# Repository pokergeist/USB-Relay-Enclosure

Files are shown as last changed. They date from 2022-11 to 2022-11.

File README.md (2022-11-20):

# USB Relay Enclosure for<br>DSD Tech SH-UR01A

## Overview

The "DSD TECH  USB Relay Controller for Computer and Laptop (1CH)" lets you control a single SPDT relay via USB. I purchased my device on [Amazon](https://smile.amazon.com/dp/B09PYML6Q7). It comes (mostly) enclosed in a transparent blue case with the relay and screw terminals exposed, along with the back half of the board. The client preferred that the internals not be so accessible.

There are a number of similar designs without cases which probably use the the same board size. If the board size is different, just modify board_x, board_y, and board_height in SCAD/DSD-Encl-common.scad in OpenSCAD and render DSD-Encl-base.scad and save the STL file (Windows F5, F6, F7).

## Status

| Date | Status |
| :---: | --- |
| 2022-11-20 | Done. |
| 2022-11-18 | First release. |

## ToDo List

* -none-

## Board Extraction

The case is a clamshell design that separates with the patient use of a spudger or pen knife. There are (6) small acrylic pins that hold the halves together. The board is well supported and positioned within the case.

See the photos in [DSD-orig](assets/DSD-orig).

## The Enclosure via OpenSCAD

My enclosure was developed using OpenSCAD, a programming language that is used to render 3-D objects for visualization and export to a standard STL file, which can then be used for 3-D printing. Elements are defined parametrically so they can be modified easily and immediately visualized and printed.

My OpenSCAD code uses some Booleans that can help visualize the package.

```
SHOW_BOARD = false;    // false before exporting STL!
HIDE_SHELL = false;    // for visualizing internals
```

SHOW_BOARD shows the printed circuit board and some components. HIDE_SHELL hides the shell mostly so you can see the internal structures. OpenSCAD has a transparent feature but it doesn't seem to work well with the rounded corners.

I uses color() to highlight areas of interest. There's a final color("MediumSpringGreen") (~line 31) that applies to the entire object. This needs to be commented out to see the component colors.

I added a hz_pins_2() function to just print pins on the left (terminal block) side and left the original hz_pins() function in place.

## Files

There are two files sets that I provide:

* Enclosure Files:
  * (3) .scad files for the bottom shell, lid, and common dimensions.
* Library files with routines for unit conversions and generating circuit board images.

### External Resources

OpenSCAD tool: [OpenSCAD.org](https://openscad.org/)

The Belfry OpenSCAD Library [revarbat/BOSL](revarbat/BOSL).

Place the BOSL and mylibs dirs in your OpenSCAD libraries directory (e.g., Documents/OpenSCAD/libraries/).

### Photo

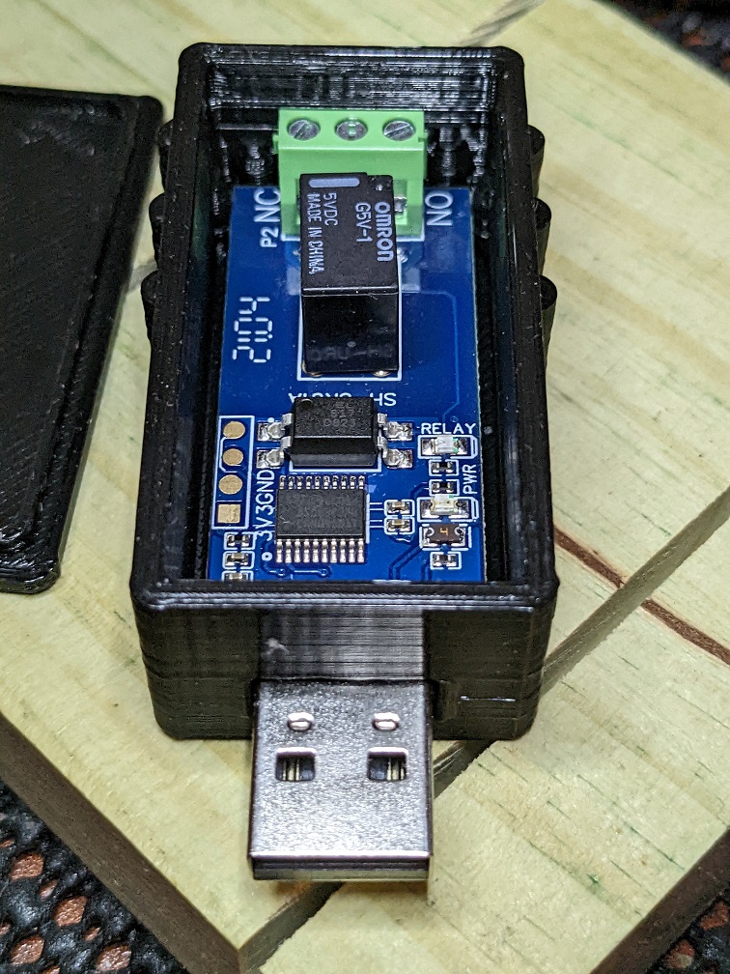
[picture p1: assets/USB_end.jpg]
DSD Item


## Fitment

The DSD board snaps snuggly into place once the USB plug end is carefully inserted through the USB window opposite of the ribbed end. Then just press down and everything should snap gently into place. There is a cable port opposite the USB window that allows you to insert wires into the NO, COM, and NC ports such that you can secure them with the terminal screws from above.

It may help to shorten the leads of the wire terminal connector with a pair of "nippy" or flush cutter pliers so that they don't catch on the edge of the enclosure, but new lower case and larger USB window has resolved the issue for me.

The lid simply snaps on.

## Operation

Relay terminals operate thusly:

* The **COM** (common) terminal is always connected to one (and only) of the other terminals at any given time.
* The **NC** (normally connected) terminal connects to the COM terminal whenever the relay **IS NOT** energized, and is isolated otherwise.
* The **NO** (normally open) terminal is normally isolated but connects to the COM terminal when the relay **IS** energized.

You would normally use the COM and NO terminals to simulate a switch. The contacts are not polarized so connect either contact (tip or ring if using 1/8"/3.5mm plugs).

For software operation please refer to vendor's documentation.

## Wire Connection Terminal

The three terminal wire connector appears to be a TE Connectivity/AMP #[1546551-3](https://www.digikey.com/short/0d5nwh74). 3-terminal 0.138"/3.5mm pitch, 120A 300V suitable for #16-28AWG wire ... or a clone. The screws are vertical so they can be manipulated with the lid removed.

The solder holes are not very big - TE recommends 1.1mm PCB holes for the connector's solder pins - just barely larger than #18AWG. I'll get a measurement on the solder holes soon.

## 1/8"/3.5mm Mono (TS) Cables

TS cables use the tip and sleeve contacts of a monophonic 1/8"/3.5mm "headphone" plug. A stereo plug is a "TRS" plug. TRS stands for Tip, Ring, & Sleeve since there is a third center contact giving you Left, Right and Ground. If you use a stereo (TRS) plug with a mono (TS) jack you'll have to verify whether the mono sleeve contact connects with the stereo sleeve (most common) or ring contact.

Here's a Digi-Key [search]() of 1/8" jacks terminated in a "pigtail", stripped wires. Length from 1 to 10'. Mono cables and jacks are scarce here - just be consistent if you use TRS hardware, or verify the mapping between TS and TRS hardware.

Amazon may offer a better selection - like this [one](https://smile.amazon.com/Fancasee-Replacement-Female-Connector-Repair/dp/B07Y8KR21P).

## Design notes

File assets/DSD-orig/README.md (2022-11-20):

# DSD Original Enclosure

## Images

### Complete

Here's the DSD device with the case separated slightly. You can see that the relay, terminal block, and about half of the board are exposed.

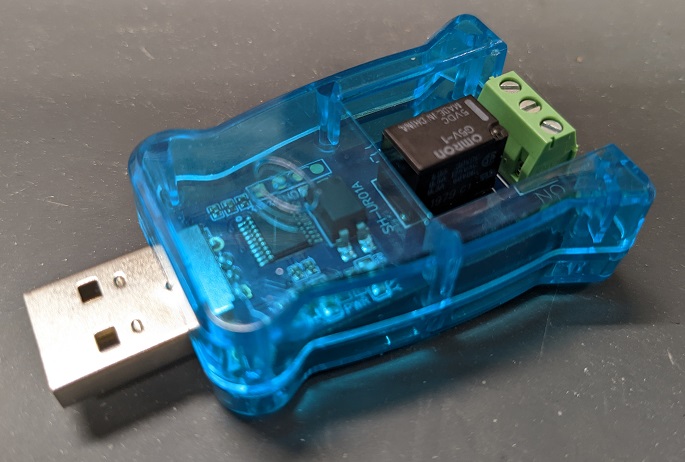
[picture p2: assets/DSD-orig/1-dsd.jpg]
complete


Here you can see the pins that hold the case together.

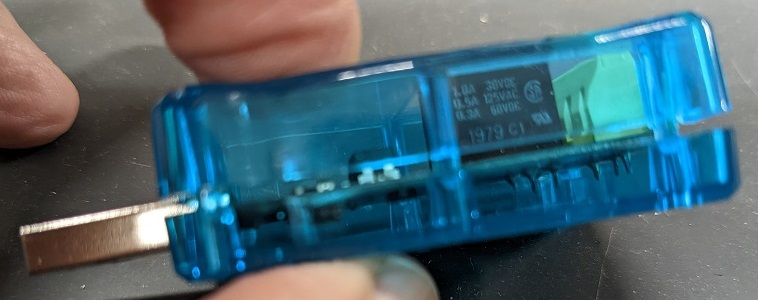
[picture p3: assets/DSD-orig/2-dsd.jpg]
pins


The top half of the case has been removed. It sits nicely supported and constrained in the base.

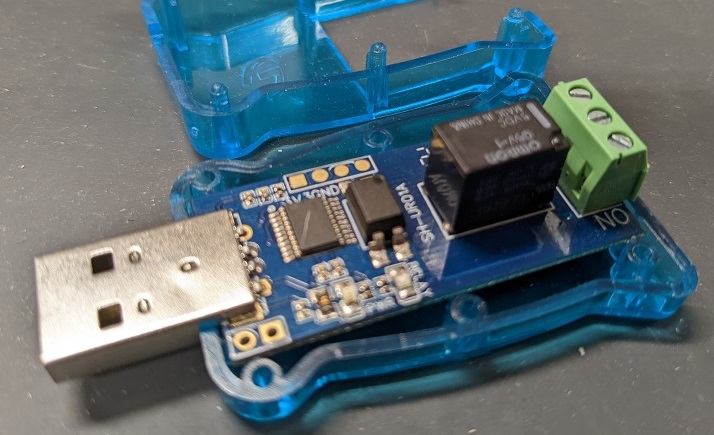
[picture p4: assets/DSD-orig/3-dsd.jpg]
in base


Here's the board with the case removed.

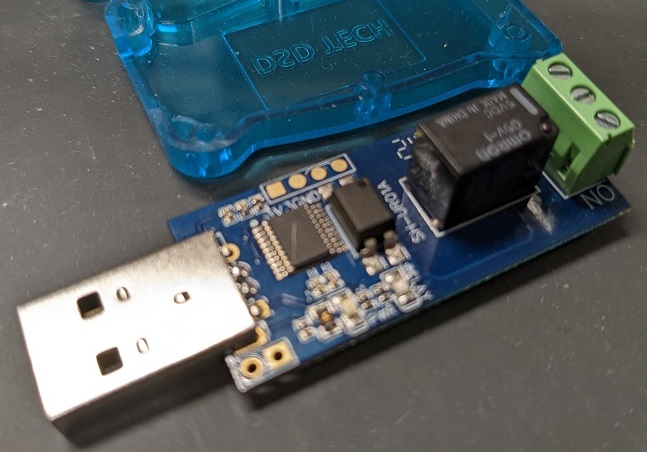
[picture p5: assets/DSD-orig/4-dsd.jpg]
board


And finally the bottom of the board. You can see labeling of the terminals and that there's no interference for board supports at the corners. The empty solder terminals connect to USB Vcc and ground.

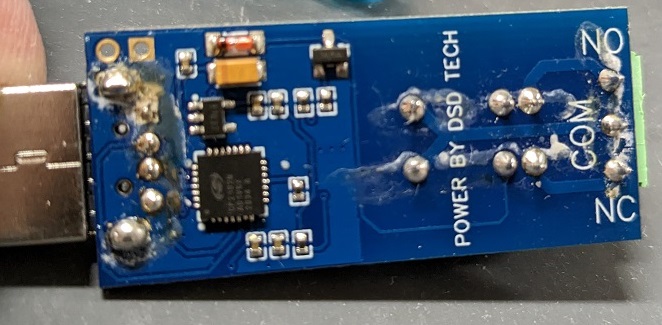
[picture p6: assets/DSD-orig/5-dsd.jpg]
bottom


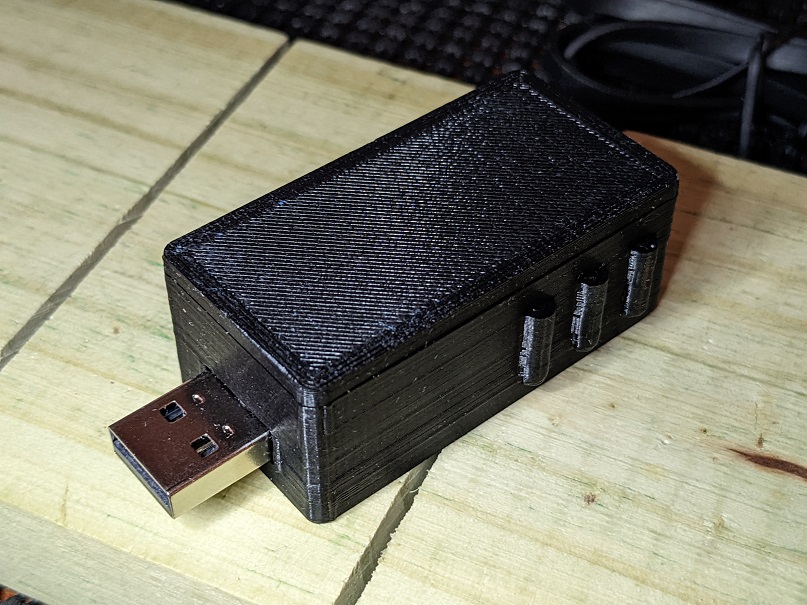
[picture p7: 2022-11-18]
assets/closed.jpg

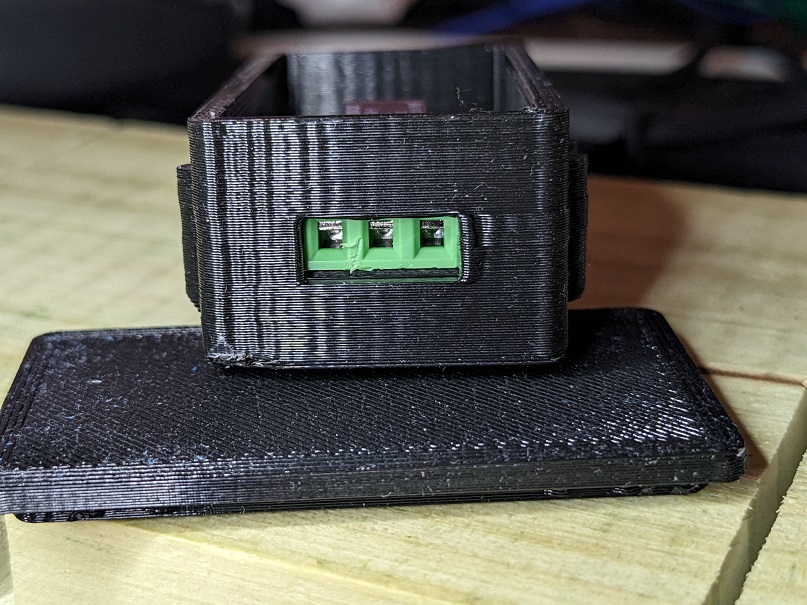
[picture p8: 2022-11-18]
assets/wire_terminals.jpg

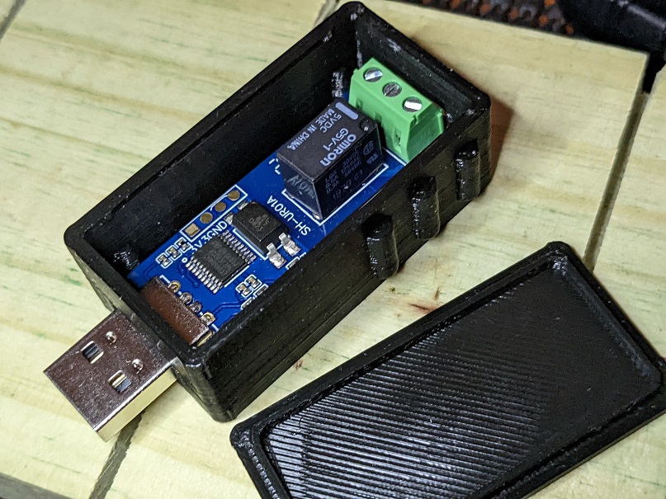
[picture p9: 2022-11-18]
assets/side.jpg

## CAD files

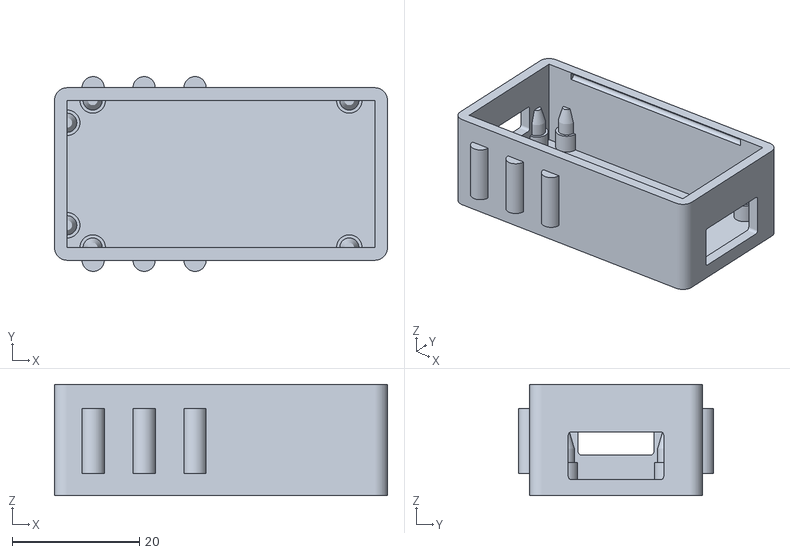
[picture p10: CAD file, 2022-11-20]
SCAD/STL/DSD-Encl-base.stl
52.3 x 30.6 x 17.5

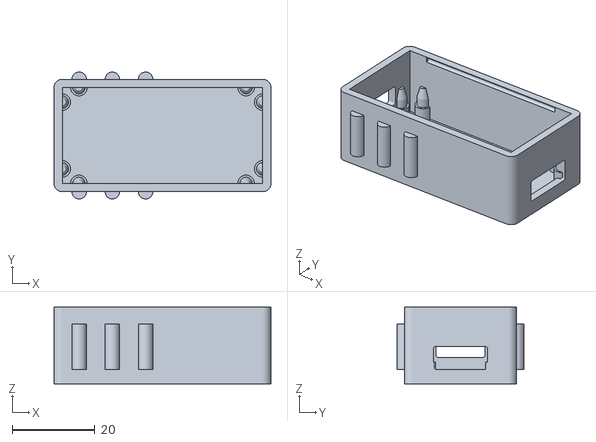
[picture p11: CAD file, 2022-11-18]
SCAD/STL/DSD-Encl-bot.stl
52.3 x 30.6 x 18.5

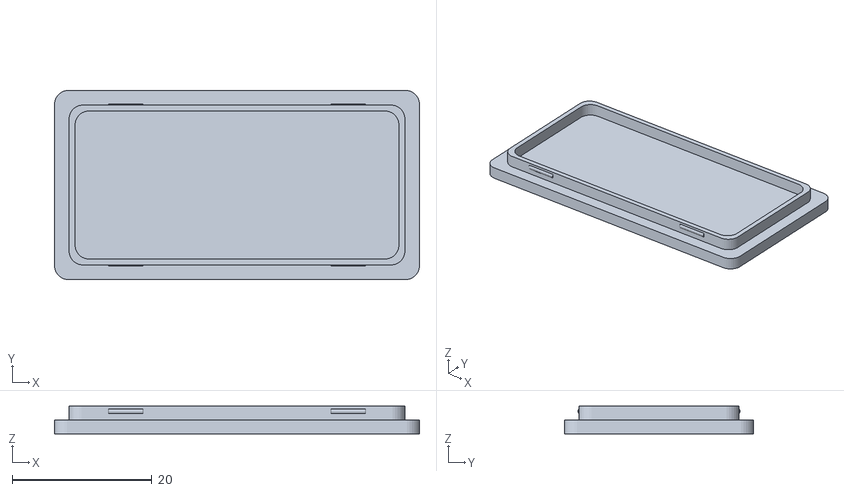
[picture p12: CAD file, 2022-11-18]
SCAD/STL/DSD-Encl-lid.stl
52.3 x 27.1 x 4.00

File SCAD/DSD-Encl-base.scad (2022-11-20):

/*
 * DSD Tech USB Relay Enclosure - Base
 */

/********************************************************
 * Objects are placed with bottom on the XY plane using
 * align=V_TOP. This eliminates a lot of up(obj_z/2)
 * moves. The floor of the box becomes the new reference
 * plane. Posts are placed on the floor, board is placed
 * on top of the posts, etc.
 ********************************************************/

// screw terminals: https://www.digikey.com/short/zwvczvrt

include <BOSL/constants.scad>
use <BOSL/shapes.scad>
use <BOSL/transforms.scad>

include <mylibs/components.scad>

include <DSD-Encl-common.scad>

ridge_offset = 0.75;
ridge_dia = 1.25;

$fn = 50;

SHOW_BOARD = false;    // false before exporting STL!
HIDE_SHELL = false;    // for visualizing internals

color("MediumSpringGreen")
build_it();     // MAIN 

module build_it() {
  // internal board
  if (SHOW_BOARD) {
    solder_holes(-board_x/2+1.7, 0, t_pcb);
    usb();
    // USB IC
    component_rect(3.5, 6.5, 2,
              "black",
              +12, -3, t_pcb);
    // MOSFET
    component_rect(3, 5, 3.5,
          "black",
          2, -1, t_pcb);
    // relay
    component_rect(relay_z, relay_y, relay_z,
              "DarkSlateGrey",
              -((board_x-relay_x)/2-8.1), 0, t_pcb);
    board();
  } //SHOW_BOARD

  // enclosure
  color("red")
  hz_pins_2();  // just two pins on the left now
  color("blue")
  vert_pins();

  if (! HIDE_SHELL) {
 
    difference() {
      color("MediumSpringGreen")
      shell();

      // usb plug port
      echo(usb_dz=usb_dz)
      window(box_wall+0.2, usb_y+wru, usb_z+wru,
             EDGES_X_ALL,
             (box_x + box_wall)/2,
             usb_dy, usb_dz2);   

      // cable port
      window(box_wall+0.2, cable_port_y, cable_port_z,
             EDGES_X_ALL, -(box_x + box_wall)/2,
             0, t_pcb+cable_port_z/2);    
    }
  } // HIDE_SHELL
} // build_it()

module usb () {
  color("silver")
  translate([usb_dx, usb_dy, usb_dz])
  cuboid([usb_x, usb_y, usb_z], align=V_TOP);
}

module board () {
  up(post_height)
  color("green")
  cuboid([board_x, board_y, pcb_thickness], align=V_TOP);
}

module solder_holes(dx, dy, dz) {
  translate([dx, dy, dz])
  grid2d(rows=3, cols=1, spacing=[0, 3.5])
  color("gold")
  down(0.8)
  cyl(d=1.8, h=1.9);
}

module window (x, y, z, edg, dx, dy, dz) {
  translate([dx, dy, dz])
  cuboid([x, y, z], fillet=box_wall/4,
         edges=edg);
}

// combo post for support, pin for contraint, & guide pin
module vert_pins() {
  // guide (pointy) pin
  pposts(pin_dia, post_dx, post_dy, post_height + pin_ht,
         2,2);
  // constraint pin
  up(post_height)
  posts(pin_dia, pin_ht, post_dx, post_dy, 2, 2);
  // support post
  posts(post_dia, post_height, post_dx, post_dy, 2, 2);
}

// combo post for support, pin for contraint, & guide pin
// only on left (terminal) side
module hz_pins_2() {
  // guide (pointy) pin
  left(hpost_dx/2) {
    pposts(pin_dia, hpost_dx, hpost_dy, post_height + pin_ht,
           2, 1);
    // constraint pin
    up(post_height)
    posts(pin_dia, pin_ht, hpost_dx, hpost_dy, 2, 1);
    // support post
    posts(post_dia, post_height, hpost_dx, hpost_dy, 2, 1);
  }
}

// combo post for support, pin for contraint, & guide pin
module hz_pins() {
  // guide (pointy) pin
  pposts(pin_dia, hpost_dx, hpost_dy, post_height + pin_ht,
         2, 2);
  // constraint pin
  up(post_height)
  posts(pin_dia, pin_ht, hpost_dx, hpost_dy, 2, 2);
  // support post
  posts(post_dia, post_height, hpost_dx, hpost_dy, 2, 2);
}

module posts(dia, height, dx, dy, r, c) {
//  grid2d(rows=2, cols=2, spacing=[box_x-box_wall, box_y-box_wall])
  grid2d(rows=r, cols=c, spacing=[dx, dy])
  cyl(d=dia, h=height, align=V_TOP);
}

module pin(dx, dy) {
  translate([dx, dy, 0]) {
    up(post_height)
    cyl(d=pin_dia,  h=pin_height, align=V_TOP);
    cyl(d=post_dia, h=post_height, align=V_TOP);
  }
}

module pposts(dia, dx, dy, dz, r, c) {
  translate([0, 0, dz])
  grid2d(rows=r, cols=c, spacing=[dx, dy])
  cyl(d1=dia, d2=dia/2, h=dia*0.85, align=V_TOP);
}

module notches(dia, len, dy) {
  grid2d(rows=2, cols=1, spacing=[0, dy])
  translate([-len/2, 0, box_height-ridge_offset])
  rotate([0, 90, 0])
  cylinder(d=dia, h=len);
}

module ribs(dx, dy, dz) {
  grid2d(rows=2, cols=3, spacing=[8, box_y+box_walls])
  translate([-box_x/4, 0, 1.5])
  cylinder(d=3.5, h=box_height*.66);  
}

module shell() {
  echo("box X=", box_x+box_walls)
  echo("box X", box_y+box_walls)
  echo("box Z", box_height+box_wall);
  ribs();
  difference() {
    down(box_wall)  // box floor is the reference plane
    cuboid([box_x+box_walls, box_y+box_walls, box_height+box_wall],
           align=V_TOP, fillet=2, edges=EDGES_Z_ALL);

    cuboid([box_x, box_y, box_height+box_wall], align=V_TOP);
    notches(ridge_dia, box_x-10, box_y);
  }
}

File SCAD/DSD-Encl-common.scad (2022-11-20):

/*
 * DSD Tech USB Relay Enclosure Dimensions
 */

pcb_thickness = 1.16;

board_x = 45.1 + 0.2; // for screw terminal overhand
board_y = 20.1;

post_height = 3.25;

t_pcb = post_height + pcb_thickness;

usb_x = 19;
usb_y = 12;
usb_z = 4.5;

usb_dx = usb_x/2+board_x/2-3.4;
usb_dy = 0;
usb_dz  = t_pcb - pcb_thickness/2 - usb_z*0.4; // for USB plug
usb_dz2 = t_pcb - pcb_thickness/2 + usb_z*0.1; // for window

wr  = 1;  // window relief
wru = 3;  // extra relief for USB port

cable_port_y = 11.9;
cable_port_z = 5.0;

relay_x = 12.45;  
relay_y = 7.3;
relay_z = 9.9;
t_relay = t_pcb + relay_z;

//bdr = 2.0;                  // board relief
bdr = 1.5;                  // board relief
box_x = board_x + bdr * 2;  // interior dimensions
box_y = board_y + bdr * 2;
box_height = t_relay+1.2;
box_wall  = 2;
box_walls = box_wall * 2;

// board support
post_dia = box_walls;
post_dx = box_x - 8;
post_dy = box_y;    // centerline of box interior
hpost_dx = box_x;
hpost_dy = box_y-7;
// board constraint
pin_dia  = box_x - board_x;
pin_ht = 2.2;

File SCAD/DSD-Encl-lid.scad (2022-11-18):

/*
 * DSD Tech USB Relay Enclosure - Lid
 */
 
include <BOSL/constants.scad>
use <BOSL/shapes.scad>
use <BOSL/transforms.scad>

include <mylibs/components.scad>

include <DSD-Encl-common.scad>

lid_height = 2;
ridge_offset = 0.75;

$fn = 30;

build_it();

module build_it() {
  color("MediumSpringGreen")
  lid();
}

module lid() {
  // clips to hole lid in place
  color("red")
  ridges(1, 5, box_y-0.9);

  difference() {
    color("purple")
    cuboid([box_x-0.2, box_y-0.2, lid_height],
           align=V_TOP, fillet=2, edges=EDGES_Z_ALL);

    // hollow out rim
    down(0.01)
    cuboid([box_x-1.9, box_y-1.9, lid_height+1],
           align=V_TOP, fillet=2, edges=EDGES_Z_ALL);
  }
  
  // lid base
  down(box_wall)
  color("orange")
  cuboid([box_x+box_walls, box_y+box_walls, lid_height],
         align=V_TOP, fillet=2, edges=EDGES_Z_ALL);
}

module ridges(dia, len, dy) {
  echo(ridge_offset=ridge_offset);
  grid2d(rows=2, cols=2, spacing=[box_x*0.66, dy])
  translate([-len/2, 0, lid_height - ridge_offset])
  rotate([0, 90, 0])
  cylinder(d=dia, h=len);
}

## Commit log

2022-11-18 initial release
    [DSD-Encl-base.scad, DSD-Encl-bot.stl, DSD-Encl-common.scad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]
2022-11-20 base & edits
    [DSD-Encl-base.stl]
2022-11-20 new pix & enclosure
    [DSD-Encl-base.scad, DSD-Encl-base.stl, DSD-Encl-common.scad]
